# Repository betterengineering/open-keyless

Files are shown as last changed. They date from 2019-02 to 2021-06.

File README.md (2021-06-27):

# Open Keyless

GoDoc (https://godoc.org/github.com/betterengineering/open-keyless)

Open Keyless is a keyless entry system for contactless key cards. This project includes all of the necessary software,
printed circuit board designs, 3D models, and documentation to build an RFID based badge reader and controller.

Note: this project is under development and has not yet been completed. Once a functioning version of this
project exists, this message will be removed and the release will be added as a github release.

## Installation
To install the latest release, run the following from your Raspberry Pi:
```
curl -LO https://github.com/betterengineering/open-keyless/releases/latest/download/install.sh
chmod +x ./install.sh
sudo ./install.sh
```

## Documentation
The documentation for Open Keyless is kept in the repo! Checkout the [Overview](docs/overview.md) for a starting point.

## Development
This project uses Go 1.11 modules! If you have Go 1.11 or later installed, no other project setup is necessary.

### Testing
To run tests locally, run the following:
```bash
make test
```

To include integration tests, run the following:
```bash
make test-full
```

### Mocks
This project uses Golang's [mockgen](https://github.com/golang/mock) tool to generate mocks for interfaces. To regenerate mocks, run the following:
```bash
make mocks
```

### Libnfc
To develop locally, you will need libnfc installed. I would like to remove this as a dependency in the future, but alas,
it is a dependency for now.

For MacOS, run the following:
```bash
brew install libnfc
```

For Debian based Linux distros, run the following:
```bash
apt-get install -y libnfc-dev
```

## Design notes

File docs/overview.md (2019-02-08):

# Overview
This project contains two modules: a [reader](reader.md) and a [controller](controller.md). The reader module is meant
to sit on the outside of the door to scan RFID badges and the controller sits on the inside of the door to control the
electric door strike and determine if the user has access.

At the time of writing, this system is a one to one mapping in that one controller can only service one reader. This
project will likely be extended in the next iteration to support more reader/controller combinations and may require
a centralized controller to allow for many badge readers.

## Cost
At the time of writing, I calculated the cost for building the reader and controller using all links provided to be
about $200 USD ($208.55 to be precise) including shipping. Your end cost may vary. This project was not optimized for
cost in the current iteration, so this could easily be optimized to be lower.

This cost does not include the electric strike. The electric strike will likely be the most expensive part of this
build. I've seen electric strikes vary from $50 to $400 USD depending on the grade and use case of the strike, so keep
that in mind.

If this project acquires enough interest, I would be willing to sell assemble it yourself kits with a slight markup that
would lower the cost of overall because I could buy in bulk.

## Printed Circuit Boards
This project contains several printed circuit boards (PCBs) that need to be manufactured. These boards were designed
using [Eagle](https://www.autodesk.com/products/eagle/overview) and can be found in the `/assets` directory in this
repository. If you don't have a PCB manufacturer of choice, I recommend using [OSH Park](https://oshpark.com/). They are
well made and inexpensive. They do have a minimum order of 3 units, but I have found the final cost to be so low
($2-$4 USD per board and free shipping) that 3 units is still affordable even if you only need one.

In each module guide, I have included a shared project link that you can order directly from OSH Park without needing to
upload the `.brd` file.

## 3D Printed Housing
This project contains several 3D models that need to be manufactured. These models were designed via
[Onshape](https://www.onshape.com/) and can be found publicly
[here](https://cad.onshape.com/documents/67f068fc5317736e5689dda5/w/9dc79127656737c6368d36b9/e/1df9f27c5d40799b76486afd).
Additionally, I have included the models in SolidWorks and Parasolid formats in the `/assets` directory of this repo 
for convenience. If you don't have a 3D printing service of choice, I recommend
[Voodoo Manufacturing](https://voodoomfg.com/). They offer reasonable prices for 3D printing services.

Unfortunately, Voodoo does not currently have the functionality to allow me to host the project for ordering, so you
will need to upload the `.stl` files to Voodoo in order to order the parts needed.

## Components
I have a preference for [Adafruit](https://www.adafruit.com/) for electronics components and
[McMaster-Carr](https://www.mcmaster.com/) for physical components. All components linked in this guide should give you
enough details to swap out components from other suppliers or from components you have on hand and there is no
requirement to order from either supplier.

## See Also
* [Reader Overview](reader.md) - An overview and guide for the Open Keyless Reader module
* [Contorller Overview](controller.md) - An overview and guide for the Open Keyless Controller module

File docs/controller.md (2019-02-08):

# Open Keyless Controller
The Open Keyless Controller is designed to go on the inside of the entryway. This is to keep access to the GPIO pins on
the Raspberry Pi and the connections to the [electric door strike](strike.md) inside a secured area.

An electric door strike will need to be purchased to match your door frame and handle and is not included in this
module's parts list. For more information on choosing an electric strike, see the guide on
[Strike Buying Guide](strike.md).

## Parts List
TODO: add the housing once complete.
* [Open Keyless Controller HAT](https://oshpark.com/shared_projects/oWPmcOqR)
    * Also can be found in [assets/controller/pcbs/controller-HAT.brd](../assets/controller/pcbs/controller-HAT.brd)
    * This part will need to be manufactured. For more info, see the [overview](overview.md)
* [Breadboard-friendly 2.1mm DC barrel jack](https://www.adafruit.com/product/373)
* 1M0 / 1M ohm Resistor
    * I don't currently have a recommendation for where to pick these up. I had one on hand in my pack of resistors.
    * TODO: either redesign the controller to not need this resistor or find a reasonable supplier that wouldn't add
      another shipping fee.
* [5V 2.5A Switching Power Supply with 20AWG MicroUSB Cable](https://www.adafruit.com/product/1995)
    * This is to power the Raspberry Pi. If you already have a power source, you will not need one of these.
* [N-channel power MOSFET - 30V / 60A](https://www.adafruit.com/product/355)
* [Tapered Heat-Set Inserts for Plastic](https://www.mcmaster.com/94180a321)
    * Brass, M2.5 x 0.45 mm Thread Size, 3.4 mm Installed Length
    * This pack comes with enough for both the reader and controller. If you're building both, you only need to order
      this once.
* [Brass Heat-Set Inserts for Plastic](https://www.mcmaster.com/94459a130)
    * M3 x 0.50 mm Thread Size, 4.300 mm Installed Length
    * This pack comes with enough for both the reader and controller. If you're building both, you only need to order
      this once.
* [Stainless Steel Tamper-Resistant Button Head Torx Screws](https://www.mcmaster.com/91900a847)
    * M3 x 0.50mm Thread, 8mm Long
    * This pack comes with enough for both the reader and controller. If you're building both, you only need to order
      this once.
    * Note, if you don't have a tool for security torx screws and don't need the added security, these are a fine
      alternative: [Button Head Hex Drive Screw](https://www.mcmaster.com/92095a181)
* [White Nylon Screw and Stand-off Set – M2.5 Thread](https://www.adafruit.com/product/3658)
    * This pack comes with enough for both the reader and controller. If you're building both, you only need to order
      this once.
* [6-pin JST SM Plug + Receptacle Cable Set](https://www.adafruit.com/product/1665)
    * This pack comes with enough for both the reader and controller. If you're building both, you only need to order
      this once.
* [2-pin JST SM Plug + Receptacle Cable Set](https://www.adafruit.com/product/2880)
* [GPIO Header for Raspberry Pi HAT - 2x20 Short Female Header](https://www.adafruit.com/product/2243)
* [12V DC 1000mA (1A) regulated switching power adapter - UL listed](https://www.adafruit.com/product/798)
* [Raspberry Pi Zero W](https://www.adafruit.com/product/3400)
    * You may also need a [Mini HDMI Plug to Standard HDMI Jack Adapter](https://www.adafruit.com/product/2819) if you
      want to be able to configure the Raspberry Pi manually.
    * You may also need a [USB OTG Host Cable - MicroB OTG male to A female](https://www.adafruit.com/product/1099) if you
      want to be able to configure the Raspberry Pi manually.
* [Micro SD Card](https://www.adafruit.com/product/3259)
    * I typically buy my Micro SD cards from Amazon. I have included a link to Adafruit to limit suppliers, but any
      micro SD card over 8 GB will do.

## Assembly Guide
TODO: complete the assembly guide.

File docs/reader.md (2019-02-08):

# Open Keyless Reader
The Open Keyless Reader module is designed to go on the outside of a entryway. Because this is outside of the area of
which it is controlling access, only the RFID reader and small piezo speaker is contained in this module. All other
components, including the connection to the electric door strike is contained in the
(Open Keyless Controller)[controller.md]. If you find a security flaw or an optimization for the current design, feel
free to open a Github issue or pull request.

## Parts List
* [Open Keyless Reader PCB](https://oshpark.com/shared_projects/OfkQ6V1b)
    * Also can be found in [assets/reader/pcbs/reader.brd](../assets/reader/pcbs/reader.brd)
    * This part will need to be manufactured. For more info, see the [overview](overview.md)
* [Open Keyless Reader Housing Front](../assets/reader/housing/front/reader-housing-front.stl)
    * This part will need to be manufactured. For more info, see the [overview](overview.md)
* [Open Keyless Reader Housing Back](../assets/reader/housing/back/reader-housing-back.stl)
    * This part will need to be manufactured. For more info, see the [overview](overview.md)
* [Tapered Heat-Set Inserts for Plastic](https://www.mcmaster.com/94180a321)
    * Brass, M2.5 x 0.45 mm Thread Size, 3.4 mm Installed Length
    * This pack comes with enough for both the reader and controller. If you're building both, you only need to order
      this once.
* [Brass Heat-Set Inserts for Plastic](https://www.mcmaster.com/94459a130)
    * M3 x 0.50 mm Thread Size, 4.300 mm Installed Length
    * This pack comes with enough for both the reader and controller. If you're building both, you only need to order
      this once.
* [Stainless Steel Tamper-Resistant Button Head Torx Screws](https://www.mcmaster.com/91900a847)
    * M3 x 0.50mm Thread, 8mm Long
    * This pack comes with enough for both the reader and controller. If you're building both, you only need to order
      this once.
    * Note, if you don't have a tool for security torx screws and don't need the added security, these are a fine
      alternative: [Button Head Hex Drive Screw](https://www.mcmaster.com/92095a181)
* [6-pin JST SM Plug + Receptacle Cable Set](https://www.adafruit.com/product/1665)
    * This pack comes with enough for both the reader and controller. If you're building both, you only need to order
      this once.
* [2.54mm/0.1" Pitch Terminal Block - 2-pin](https://www.adafruit.com/product/2138) x 2
* [Large Enclosed Piezo Element w/Wires](https://www.adafruit.com/product/1739)
* [36-pin 0.1" Female header - pack of 5!](https://www.adafruit.com/product/598)
    * The reader only actually requires one 6 pin segment if you already have these lying around
* [PN532 NFC/RFID controller breakout board - v1.6](https://www.adafruit.com/product/364)
* [White Nylon Screw and Stand-off Set – M2.5 Thread](https://www.adafruit.com/product/3658)
    * This pack comes with enough for both the reader and controller. If you're building both, you only need to order
      this once.

## Assembly Guide
TODO: complete the assembly guide.

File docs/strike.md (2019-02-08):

# Strike Buying Guide
This project requires a 12v Electric Strike. I bought
[this one](https://www.amazon.com/gp/product/B004HN48BI/ref=ppx_yo_dt_b_asin_title_o09__o00_s00?ie=UTF8&psc=1) on
Amazon for about $50 USD.

TODO: populate the strike buying guide with examples, images, and links.

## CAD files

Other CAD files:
assets/reader/housing/back/reader-housing-back.sldprt
assets/reader/housing/front/reader-housing-front.sldprt
assets/reader/housing/back/reader-housing-back.stl
assets/reader/housing/back/reader-housing-back.x_t
assets/reader/housing/front/reader-housing-front.stl
assets/reader/housing/front/reader-housing-front.x_t

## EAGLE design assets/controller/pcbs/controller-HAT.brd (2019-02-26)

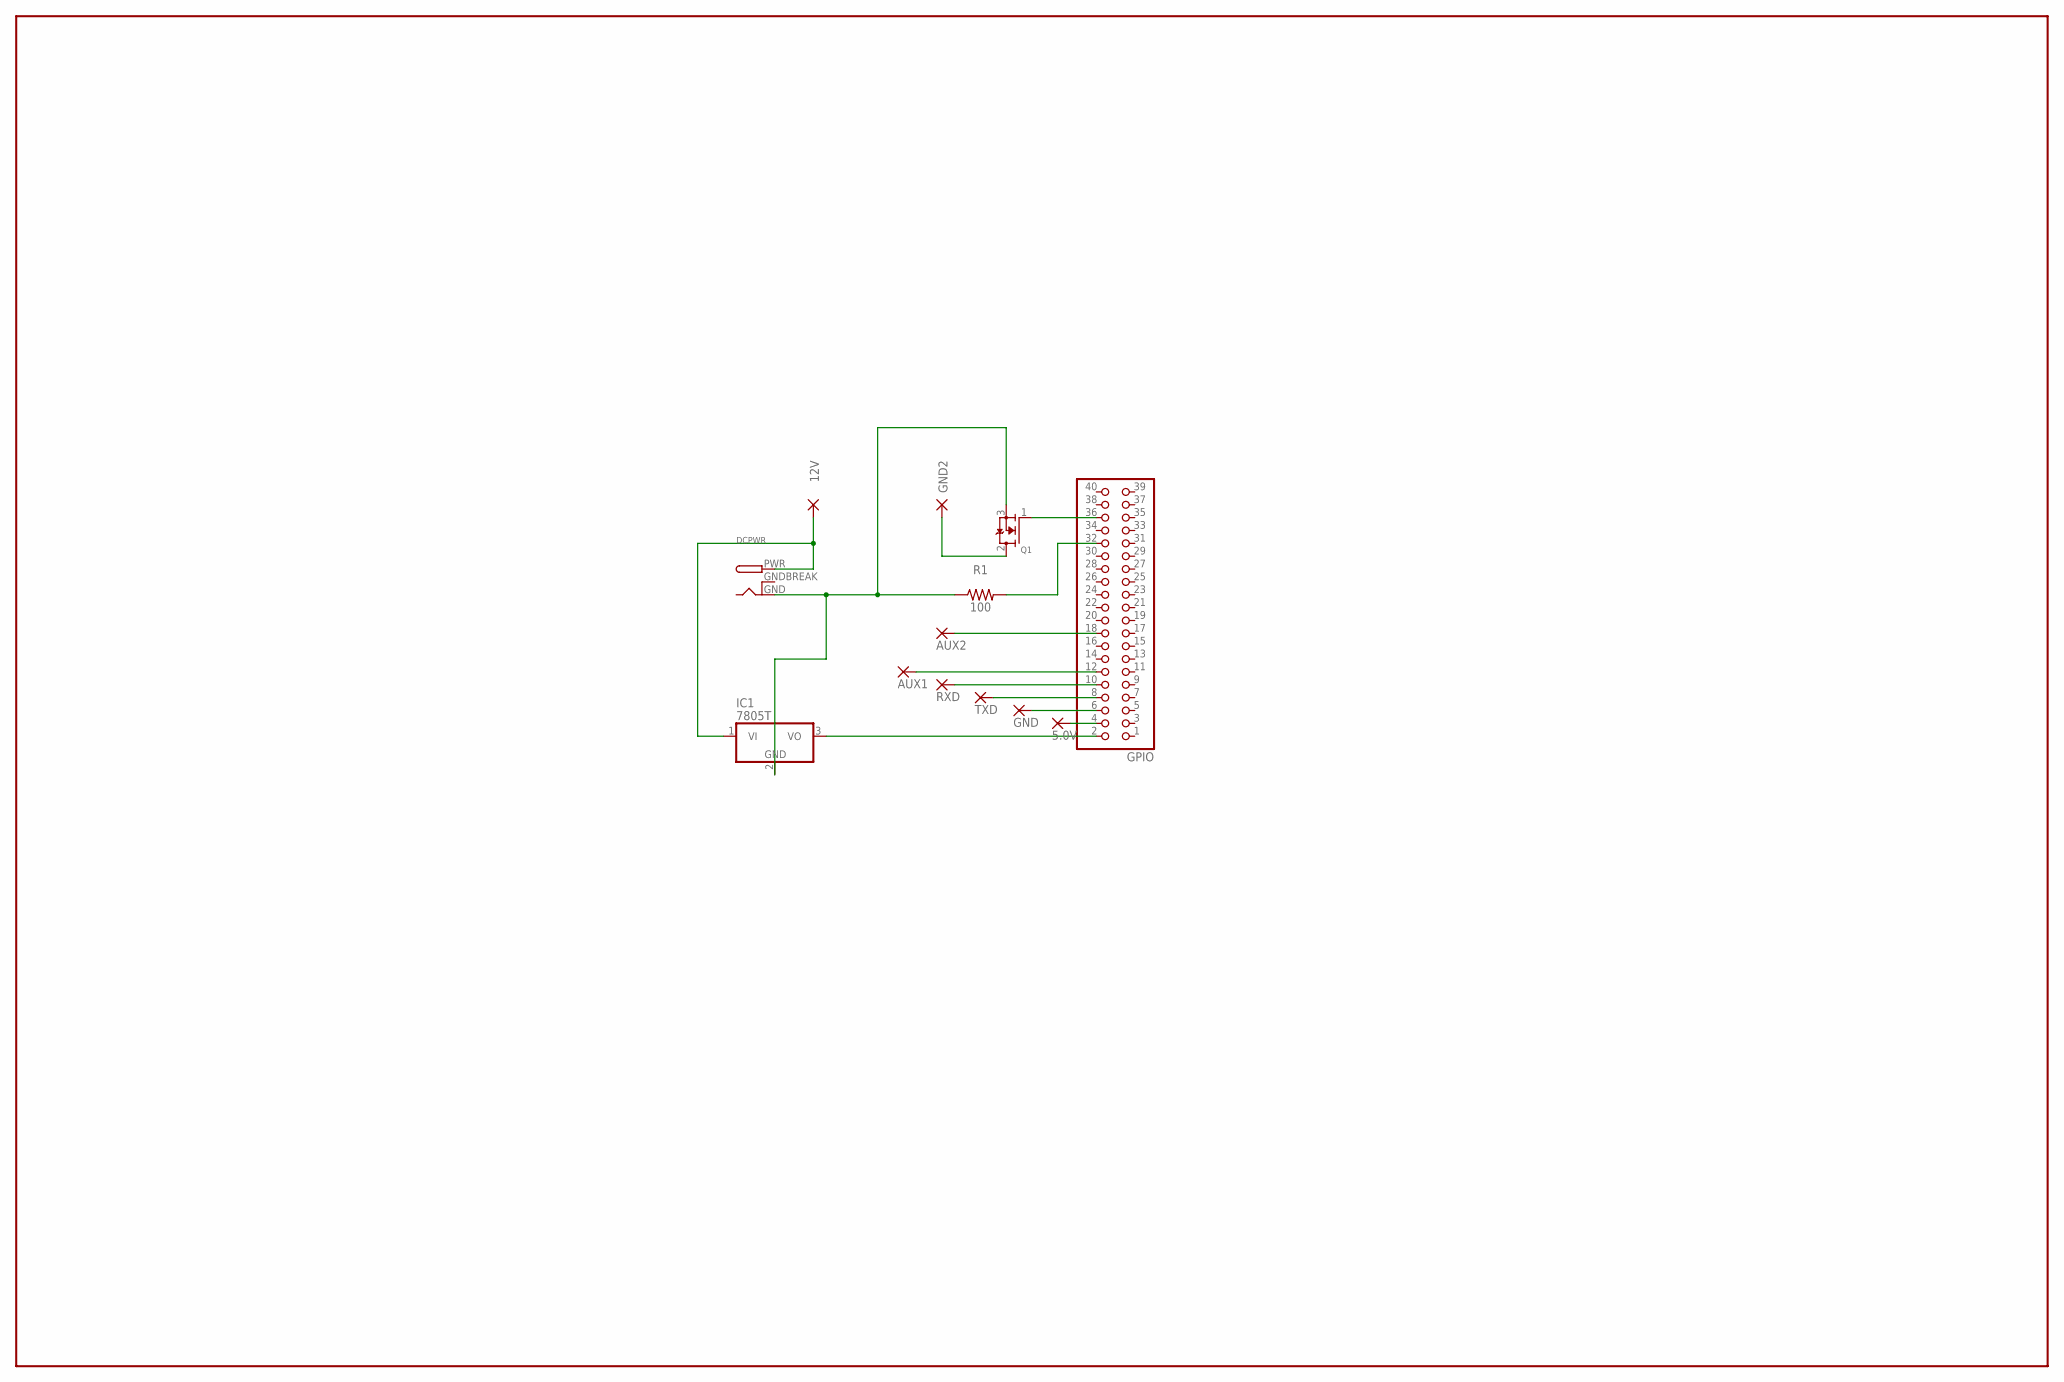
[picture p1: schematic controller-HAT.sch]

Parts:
5.0V, 12V: 1,6/0,9
AUX1, AUX2: 1,6/0,9
DCPWR: DCBARRELPTH; DCJACK_2MM_PTH
GND, GND2: 1,6/0,9
GPIO: PINHD-2X20; 2X20
IC1: 7805T; TO220H
Q1: MOSFET-NGDS_TO220V; TO220V
R1: 100; AXIAL-0.3
RXD: 1,6/0,9
TXD: 1,6/0,9

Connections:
GNDBREAK: DCPWR.GNDBREAK
unnamed: GND2.1, Q1.2 (D)
unnamed: 12V.1, DCPWR.PWR, IC1.1 (VI)
unnamed: GPIO.32, R1.P$2 (2)
unnamed: DCPWR.GND, IC1.2 (GND), Q1.3 (S), R1.P$1 (1)
unnamed: GPIO.36, Q1.1 (G)
unnamed: 5.0V.1, GPIO.4
unnamed: GND.1, GPIO.6
unnamed: GPIO.8, TXD.1
unnamed: GPIO.10, RXD.1
unnamed: AUX1.1, GPIO.12
unnamed: AUX2.1, GPIO.18
unnamed: GPIO.2, IC1.3 (VO)

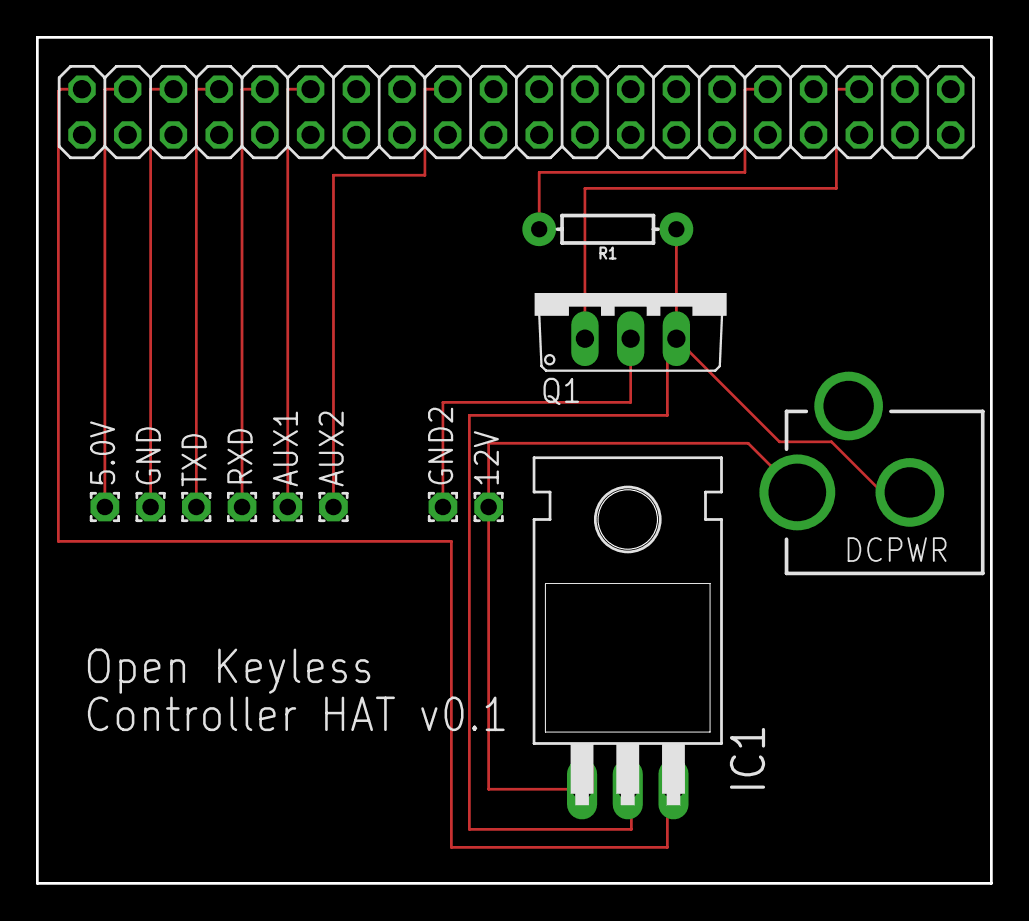
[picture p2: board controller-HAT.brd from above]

Board: 2 copper layers, 53.0 x 47.0 mm, 13 parts (0 on the bottom side), 12 nets.

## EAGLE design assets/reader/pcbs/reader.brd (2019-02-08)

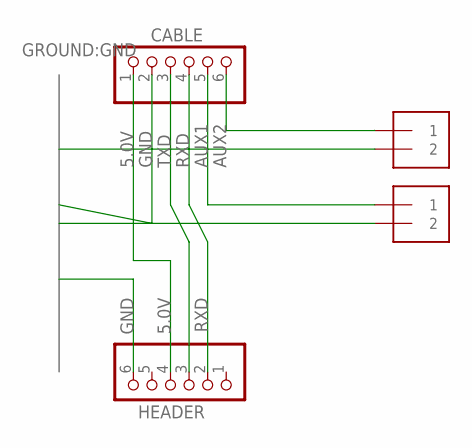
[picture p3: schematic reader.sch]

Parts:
AUX1, AUX2: 1X2-3.5MM
CABLE: PINHD-1X6; 1X06
HEADER: PINHD-1X6; 1X06

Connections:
5.0V: CABLE.1, HEADER.4
AUX1: AUX1.1, CABLE.5
AUX2: AUX2.1, CABLE.6
GND: AUX1.2, AUX2.2, CABLE.2, HEADER.6
RXD: CABLE.4, HEADER.2
TXD: CABLE.3, HEADER.3

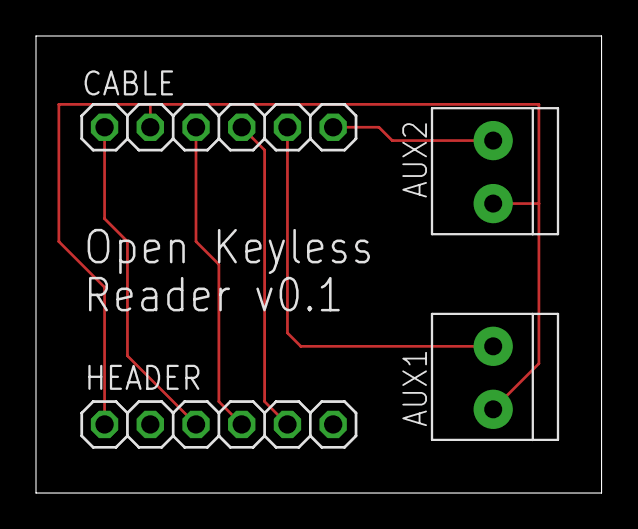
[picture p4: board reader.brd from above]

Board: 2 copper layers, 31.4 x 25.4 mm, 4 parts (0 on the bottom side), 6 nets.

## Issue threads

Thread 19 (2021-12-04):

Please update your NFC dependency

clausecker, 2021-12-04:
Hello,

I'm the author of the NFC package you are using.  A while ago, I have migrated this package to Go modules and moved my Github account from `fuzxxl` to `clausecker`.  Please upgrade your NFC dependency from

    github.com/fuzxxl/nfc/2.0/nfc

to the current one

    github.com/clausecker/nfc/v2

Apart from the import path change (to make the path compliant with Go module syntax), no incompatible API changes have occurred.
You might also need libnfc version 1.8.0 or newer for this to work.

The old dependency might go away at some point in the future.

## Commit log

2019-01-22 Added a package for an electric strike.
    This commit adds infrastructure for mocks and adds a package for an electric
    strike with an implementation for the Raspberry pi.
2019-02-08 Added v0.1 assets.
    This commit adds the version 0.1 hardware designs for Open Keyless with the
    exception of the controller housing that is still being designed. Additionally,
    this commit adds a blurb about versioning to the readme.
    [controller-HAT.brd, controller-HAT.sch, reader-housing-back.sldprt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]
2019-02-09 Added debian packaging.
    This commit adds debian packaging to this project. The resulting debian package
    contains the go binary compiled for ARM and a systemd unit file.
2019-02-26 Updated the controller hat.
    This commit updates the controller hat to include a voltage regulator. This will
    allow a single, 12v power source to power both the strike and the raspberry pi
    through the 5v pin.
    [controller-HAT.brd, controller-HAT.sch]
2019-11-05 Updated build.
    Updated build to use go 1.13 and new Google Cloud bucket.
2021-06-27 Added an install script.
    I still need to test this on the device.

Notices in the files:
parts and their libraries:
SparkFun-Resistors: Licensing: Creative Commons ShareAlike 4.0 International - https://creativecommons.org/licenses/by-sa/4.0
